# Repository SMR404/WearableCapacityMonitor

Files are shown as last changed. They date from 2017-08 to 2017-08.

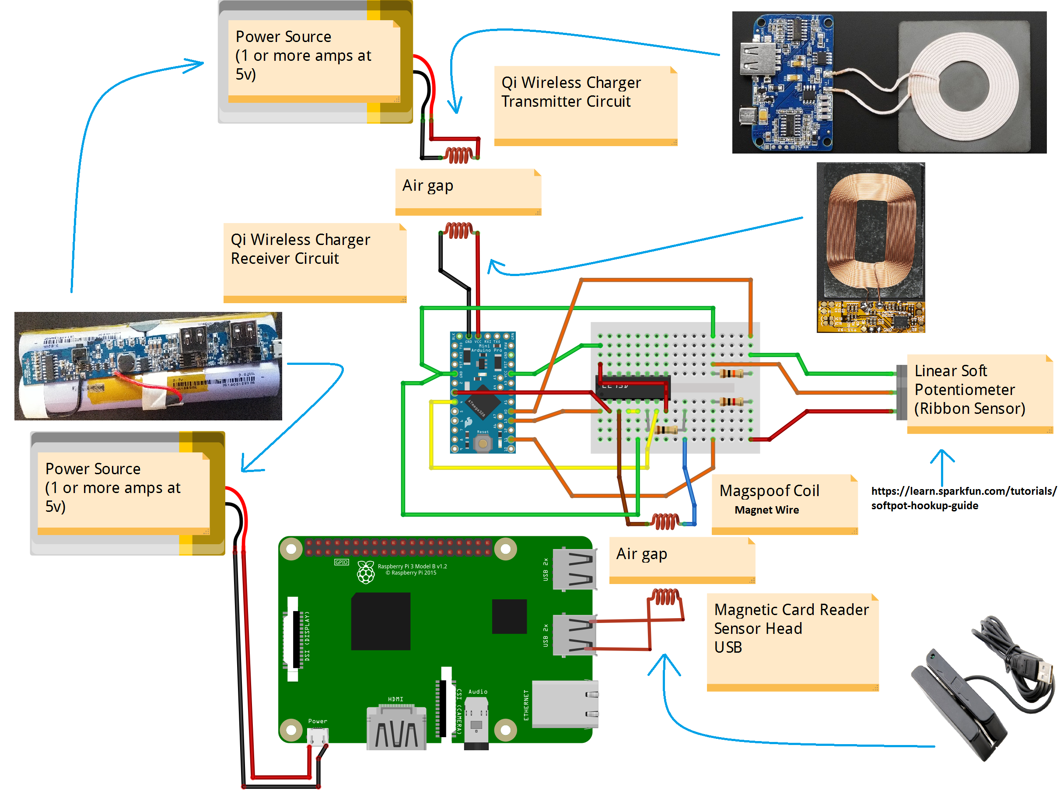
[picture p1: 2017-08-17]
diagrams/Diagram.png

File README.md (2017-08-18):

# BT_CapacityMonitor

# AR-15 Magazine Capacity Monitoring System (Proof of Concept)

This is a proof of concept for a method to display the number of rounds in an AR-15's magazine on an Android device or Android-Wear device using bluetooth for data transfer from Raspberry Pi to android and using a modified version of Samy Kamkar's (@samyk) magspoof for data transfer between the magazine and raspberry pi. Credit to @miaoski for his conversion of the magspoof's ATtiny85's code to arduino.

**Check out my video for more information, explanations, and pictures/video.**

General Overview of project + Demonstration: https://vid.me/MMtok

I'll try and get some new videos up discussing this idea and desired improvements in depth at a (hopefully soon) future date.

## *Flow of information*

The system is composed of several components and boards.
Below is the flow of infomation from the magazine to the user.

- **Component: On Magazine - Arduino Pro Mini (or similar) with a Magspoof magnetic Card emulator (magspoof)**

 &nbsp;&nbsp;&nbsp;&nbsp;&nbsp;&nbsp;&nbsp;&nbsp;&nbsp;&nbsp;&nbsp;&nbsp;&nbsp;&nbsp;&nbsp;&nbsp;&nbsp;&nbsp;|<br>
 &nbsp;&nbsp;&nbsp;&nbsp;&nbsp;&nbsp;&nbsp;&nbsp;&nbsp;&nbsp;&nbsp;&nbsp;&nbsp;&nbsp;&nbsp;&nbsp;&nbsp;&nbsp;|<br>
 &nbsp;&nbsp;&nbsp;&nbsp;&nbsp;&nbsp;&nbsp;&nbsp;&nbsp;&nbsp;&nbsp;&nbsp;&nbsp;&nbsp;&nbsp;&nbsp;&nbsp;&nbsp;| &nbsp;&nbsp;&nbsp;&nbsp;&nbsp;&nbsp;&nbsp;&nbsp;   *Data (ultra-low baud rate) is sent wirelessly from the magazine to the card reader via magspoof* <br>
 &nbsp;&nbsp;&nbsp;&nbsp;&nbsp;&nbsp;&nbsp;&nbsp;&nbsp;&nbsp;&nbsp;&nbsp;&nbsp;&nbsp;&nbsp;&nbsp;&nbsp;&nbsp;|<br>
 &nbsp;&nbsp;&nbsp;&nbsp;&nbsp;&nbsp;&nbsp;&nbsp;&nbsp;&nbsp;&nbsp;&nbsp;&nbsp;&nbsp;&nbsp;&nbsp;&nbsp;&nbsp;|<br>
 &nbsp;&nbsp;&nbsp;&nbsp;&nbsp;&nbsp;&nbsp;&nbsp;&nbsp;&nbsp;&nbsp;&nbsp;&nbsp;&nbsp;&nbsp;&nbsp;&nbsp;▼      

- **Component: On Rifle - Magnetic Card Reader connected as a usb keyboard to the Raspberry-pi (or similar)**

 &nbsp;&nbsp;&nbsp;&nbsp;&nbsp;&nbsp;&nbsp;&nbsp;&nbsp;&nbsp;&nbsp;&nbsp;&nbsp;&nbsp;&nbsp;&nbsp;&nbsp;&nbsp;|<br>
 &nbsp;&nbsp;&nbsp;&nbsp;&nbsp;&nbsp;&nbsp;&nbsp;&nbsp;&nbsp;&nbsp;&nbsp;&nbsp;&nbsp;&nbsp;&nbsp;&nbsp;&nbsp;|<br>
 &nbsp;&nbsp;&nbsp;&nbsp;&nbsp;&nbsp;&nbsp;&nbsp;&nbsp;&nbsp;&nbsp;&nbsp;&nbsp;&nbsp;&nbsp;&nbsp;&nbsp;&nbsp;|  &nbsp;&nbsp;&nbsp;&nbsp;&nbsp;&nbsp;&nbsp;&nbsp;&nbsp;&nbsp;     *Data is sent over bluetooth serial connection from the Raspberry-pi to android*
 <br>
&nbsp;&nbsp;&nbsp;&nbsp;&nbsp;&nbsp;&nbsp;&nbsp;&nbsp;&nbsp;&nbsp;&nbsp;&nbsp;&nbsp;&nbsp;&nbsp;&nbsp;&nbsp;|<br>
 &nbsp;&nbsp;&nbsp;&nbsp;&nbsp;&nbsp;&nbsp;&nbsp;&nbsp;&nbsp;&nbsp;&nbsp;&nbsp;&nbsp;&nbsp;&nbsp;&nbsp;&nbsp;|<br>
 &nbsp;&nbsp;&nbsp;&nbsp;&nbsp;&nbsp;&nbsp;&nbsp;&nbsp;&nbsp;&nbsp;&nbsp;&nbsp;&nbsp;&nbsp;&nbsp;&nbsp;▼   

- **Component: Android Wear or other android device (or similar)**

&nbsp;&nbsp;&nbsp;&nbsp;&nbsp;&nbsp;&nbsp;&nbsp;&nbsp;&nbsp;&nbsp;&nbsp;&nbsp;&nbsp;&nbsp;&nbsp;&nbsp;&nbsp;| <br>
&nbsp;&nbsp;&nbsp;&nbsp;&nbsp;&nbsp;&nbsp;&nbsp;&nbsp;&nbsp;&nbsp;&nbsp;&nbsp;&nbsp;&nbsp;&nbsp;&nbsp;&nbsp;|<br>
&nbsp;&nbsp;&nbsp;&nbsp;&nbsp;&nbsp;&nbsp;&nbsp;&nbsp;&nbsp;&nbsp;&nbsp;&nbsp;&nbsp;&nbsp;&nbsp;&nbsp;&nbsp;|&nbsp;&nbsp;&nbsp;&nbsp;&nbsp;&nbsp;&nbsp;&nbsp; *Data is displayed to user*
<br>
&nbsp;&nbsp;&nbsp;&nbsp;&nbsp;&nbsp;&nbsp;&nbsp;&nbsp;&nbsp;&nbsp;&nbsp;&nbsp;&nbsp;&nbsp;&nbsp;&nbsp;&nbsp;|<br>
&nbsp;&nbsp;&nbsp;&nbsp;&nbsp;&nbsp;&nbsp;&nbsp;&nbsp;&nbsp;&nbsp;&nbsp;&nbsp;&nbsp;&nbsp;&nbsp;&nbsp;&nbsp;|<br>
&nbsp;&nbsp;&nbsp;&nbsp;&nbsp;&nbsp;&nbsp;&nbsp;&nbsp;&nbsp;&nbsp;&nbsp;&nbsp;&nbsp;&nbsp;&nbsp;&nbsp;▼ <br>

- **Component: Eyeballs (or similar /s)**

## The info from this point on is copied from the README.md files in each immediate subfolder in this project. Navigate to those subfolders to view each topic's information by itself.

# Topic: Android
This repo has the source code for an android-wear and regular android device app. It's more convenient to test and debug from a regular android device app in my experience.
<br>
<br>
I ran out of time to really make a competent application for android (First time android developer, here).
The current android-wear program has only been tested on my Moto 360 sport and has no menu to select the Bluetooth address of the raspberry pi
to which it connects.
This means that the bluetooth address of the pi is hardcoded (gasp) into the program and **you need to change it and then build the .apk yourself**. This is pretty much a vital feature that is missing from the app.

Ideas for improvement (on android-wear):
----------------------------------
- 1. The ability to swipe between several screens which would contain some of the below features
- 2. Bluetooth Address selection screen
- 3. Day/Night mode (on an options screen)
- 4. Power down option for rapsberry pi on options screen (requires alteration to the pi's python program)
- 5. Move the connect/disconnect button to it's own screen and auto-navigate to the capacity value display screen on connection

Debugging over Bluetooth
----------------------
If you don't know how to upload an app to an android wear device without a usb port (like the moto 360 sport), you should get familiar with bluetooth debugging.

https://medium.com/@jcdelvalle/android-wear-bluetooth-debugging-quickly-guide-ef279b84169c

Follow this guide and you should be able to upload the built apk to the watch.

**Important Note:** If you can't get adb to recognize your phone, make sure that you have connected your phone as a camera device. If that doesn't work, then try all the other types of devices it can connect as.

# Topic: Arduino
Upload the sketch to your arduino (pro mini). 
You can use @miaoski's code for debugging and making sure your
magspoof circuit works (just be aware that the digital pins used his code are different numbers).

https://github.com/miaoski/magspoof

Use the softpot test file to calibrate your magazine by putting an increasing number of rounds into the magazine
and recording the analog readings and moving them into the 1d array in the arduino code.

Reference the diagram in this repo or in @miaoski's magspoof repo to make sure that your circuit is right.
I used 24 AWG wire to make the coil for data transfer.

# Topic: Raspberry Pi BT Communication Scripts
How the communication script is setup
----------------------------------------
The communication between the android device and the raspberry-pi is enabled
through a bash script that calls two python programs through a virtual terminal. 
This script launches on the start of the desktop environment.

The desktop enviromnent seems necessary because if the bash script is called (through cron or rc.local) if
the pi has booted to command line, the magentic card reader (which is a usb keyboard)
has no interactive window to output to (input() and raw_input() throw an EOF error).

This issue could possibly be solved if the two python programs were consolidated
into one program by using multiprocessing, and then monitoring usb input at a lower level (maybe using evdev or something similar?) allowing the pi script to function properly
in CLI.

Preparing the Pi
--------------------------
Make sure you are fully updated.
Make sure that the proper bluetooth libraries are installed. Follow the first part of this guide I found to make sure you have the right stuff installed. 

   `sudo apt-get dist-upgrade` <br>
   `sudo apt-get update`<br>
   `sudo apt-get upgrade`<br>
   `sudo apt-get install bluez pi-bluetooth python-bluez`<br>

How to get the script to run on boot
-------------------------------------
1. Make sure that the android device and the pi have been paired and trusted with one another (use Raspbian GUI or bluetooth-ctl).
   <br>
   *This is a permanent action (meaning it survives across reboots) that makes it so that the pi and the android device can open a serial    connection without issues.*

2. Move the magCapacityScripts folder (from github) to the /pi/home/ directory
   - run **sudo chmod +x bluetoothCommunicationScript.sh** while in the same directory as it

3. Move launch.sh (from github) to the /pi/home/ directory. 
   - run **sudo chmod +x launch.sh** while in the same directory as it
   
4. Edit the LXDE autostart file so that launch.sh runs on boot:
   
   - add these lines
   
   **cd /home/pi**
    <br>
    **sudo ./launch.sh**
    <br>
    
    - run **sudo chmod +x launch.sh** while in the same directory as it (should not be necessary, only a redundant precaution)

In this setup, the communication script is run on the start of the desktop gui.

**Note:** For some reason, without launch.sh as an intermediary shell script, autostart does not function properly (as in, bluetoothCommunicationScript.sh is called directly from autostart). In the configuration without launch.sh, autostart functions fine if called by the user, but not if it is run on boot. Not sure why.

**Important Info:** If a modified magazine has been placed into the rifle when the pi is powered, the magstripe reader attempts to send data to the pi's usb port as it is booting. The SHIFT key is pressed by the magstripe reader when it sends it's character string through the usb port. Incidentally, the key to boot to recovery is the SHIFT key. This means that, if the 'boot to recovery by pressing shift' option is enabled, the pi will boot to recovery, probably without you noticing it if you don't have it connected to a monitor. The scripts will not run in this scenario. This issue could likely be fixed by removing the option to boot to recovery, which as far as I am aware, is only something that can be done during the raspbian installation, but I have not looked into it.

# Topic: Solid Modeling
Solid Modeling Files
----------------
Note that this assembly simply represents a proof of concept and has not been designed to fulfill any practical purpose.

It seems that the Raspberry Pi model (and only that model) does not want to load properly when the STEP or IGES file is imported. If you want to place it into the assembly again, I have a zip of that model here. I got it from https://grabcad.com/library/raspberry-pi-3-6

I had to modify the lower receiver to fit the Qi Wireless Charging Ciruit and the Magnetic card reader in a semi-acceptable fashion.
In this assembly, the lower receiver is a modified (read: has sections manually and physically cut away with a power tool) version of the New Frontier LW-15 Polymer Lower Receiver (https://newfrontierarmory.com/shop/lw-15-complete-polymer-lower-receiver/). 

**ONE REALLY IMPORTANT NOTE:**
-----------------------------
I chose this receiver because polymer is easier to cut and because it was a relatively cheap receiver, and **ABOVE ALL**, because *the serial number is located away from where the modifcations take place, and none of the 3d Printed attached parts obfuscate it.*

The serial number is near the fire selector lever, and is not on the exterior of the magazine well like you will find on many other AR-15 lower receivers.

It's a really big deal that you don't alter or cover up the serial number in any way at all if you have bought a lower receiver that has such a serial number associated with it. If you have completed an 80% complete polymer lower yourself, then it's not a problem since there is no serial number assigned to it.

This is the responsibility of you as the person who is modifying their rifle, not mine. Fair warning.

# Topic: Diagrams

Hopefully these diagrams, coupled with the videos and photos, are descriptive enough.

## Items for purchase:
- L293 Motor Driver https://www.amazon.com/NDRTJM-MSTL2930-L293D-Stepper-Driver/dp/B008XCGLNM

<br>

- Raspberry Pi 3 or Raspberry Pi Zero W

<br>

- Arduino Pro Mini or other Arduino

<br>

- Android Wear device or other Android Device (with bluetooth)

<br>

- Polymer Lower Receiver (like a New Frontier LW-15, https://newfrontierarmory.com/shop/lw-15-complete-polymer-lower-receiver/)

<br>

- Qi Wireless Charging Transmitter https://www.adafruit.com/product/2162

<br>

- Qi Wireless Charging Receiver https://www.adafruit.com/product/1901

<br>

- Magnetic Card Reader http://a.co/55RirJM

<br>

- 10 kΩ, 1 kΩ and 1Ω resistors

<br>
 
 - Battery Pack with 2 ports, both of which supplying at least 1 amp each at 5v (2 amps at 5v is preferred for the port powering the Qi wireless Charger Transmitter.
 
 <br>
 
  - BreadBoard or permaProto board (preferred)
 
 <br>
 
 - Jumper Cables or other small wires
 
 <br>
 
 - Magnet Wire (24 AWG is what I used)
 
 <br>
 
 - Bolts or Machine screws of approximate outer thread diameter of 0.3 mm (I don't know what I used, they were found leftovers)
 
 <br>
 
 - 3D printer and filament
 
  <br>
  <br>
  <br>
  
 These are just the items that are attached to/used with the gun. There are lots of other logistical items like arduino programmer chips and other things that you will need for this, but they are intuitive and are closely associated with the use of the above items.

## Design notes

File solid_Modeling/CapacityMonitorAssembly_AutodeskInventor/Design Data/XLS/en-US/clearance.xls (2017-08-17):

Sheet: Ansi Unified Screw Threads
I | Sort Order -1
Fastener Type | Size | Shaft Diameters |  |  | Head Dimensions
 |  | Close | Normal | Loose | Diameter | Depth/Angle | Head Type
Flat Head Machine Screw (82) | #0 | 0.0635 | 0.07 | 0.073 | 0.119 | 82 | 2
Flat Head Machine Screw (82) | #1 | 0.076 | 0.081 | 0.089 | 0.146 | 82 | 2
Flat Head Machine Screw (82) | #2 | 0.089 | 0.096 | 0.1065 | 0.172 | 82 | 2
Flat Head Machine Screw (82) | #3 | 0.104 | 0.11 | 0.12 | 0.199 | 82 | 2
Flat Head Machine Screw (82) | #4 | 0.116 | 0.1285 | 0.136 | 0.225 | 82 | 2
Flat Head Machine Screw (82) | #5 | 0.1285 | 0.136 | 0.154 | 0.252 | 82 | 2
Flat Head Machine Screw (82) | #6 | 0.144 | 0.1495 | 0.1695 | 0.279 | 82 | 2
Flat Head Machine Screw (82) | #8 | 0.1695 | 0.177 | 0.1935 | 0.332 | 82 | 2
Flat Head Machine Screw (82) | #10 | 0.196 | 0.201 | 0.221 | 0.385 | 82 | 2
Flat Head Machine Screw (82) | #12 | 0.221 | 0.228 | 0.246 | 0.438 | 82 | 2
Flat Head Machine Screw (82) | 1/4 | 0.257 | 0.266 | 0.2812 | 0.507 | 82 | 2
Flat Head Machine Screw (82) | 5/16 | 0.323 | 0.332 | 0.3437 | 0.635 | 82 | 2
Flat Head Machine Screw (82) | 3/8 | 0.386 | 0.397 | 0.4062 | 0.762 | 82 | 2
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

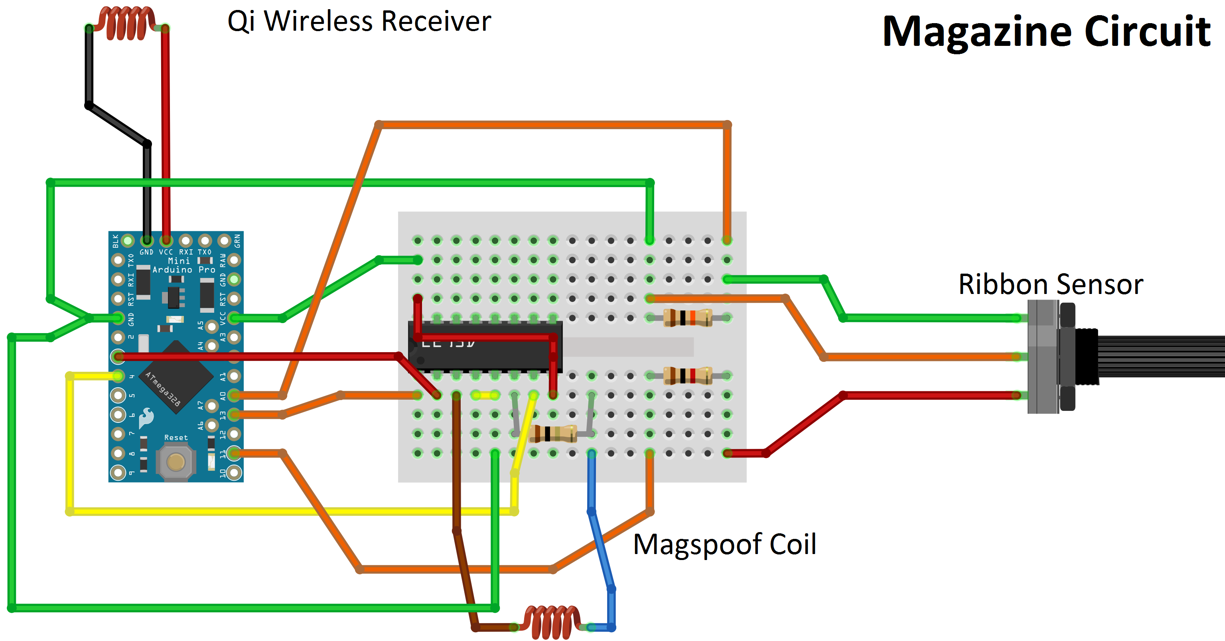
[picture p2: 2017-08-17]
diagrams/Diagram_MagazineOnly.png

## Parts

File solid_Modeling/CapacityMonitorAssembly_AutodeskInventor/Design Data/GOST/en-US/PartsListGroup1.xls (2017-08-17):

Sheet: Лист 1
Инв. № подл |  |  |  | Подп. и дата | Взам. инв. № | Инв. № дубл. |  |  | Подп. и дата
Формат | Зона | Поз. | Обозначение |  |  |  | Наименование |  |  |  |  |  | Кол. на исполнение
 |  |  |  |  |  |  |  |  |  |  |  | Лит.
 |  |  |  |  |  |  |  |  |  |  |  | Код
 |  |  |  |  |  |  |  | Изм. | Лист | № докум | Подпись |  | Дата
 |  |  |  |  |  |  |  | Разраб.
 |  |  |  |  |  |  |  | Пров.
 |  |  |  |  |  |  |  | Н.контр
 |  |  |  |  |  |  |  | Утв.
 |  |  |  |  |  |  |  |  |  |  |  |  |  | Копировал

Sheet: Лист 2
Инв. № подл |  |  |  | Подп. и дата | Взам. инв. № | Инв. № дубл. |  |  | Подп. и дата
Формат | Зона | Поз. | Обозначение |  |  |  | Наименование |  |  |  |  | Кол. на исполнение
 |  |  |  |  |  |  |  | Изм. | Лист | № докум. | Подп. | Дата
 |  |  |  |  |  |  |  |  |  |  |  |  | Копировал
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

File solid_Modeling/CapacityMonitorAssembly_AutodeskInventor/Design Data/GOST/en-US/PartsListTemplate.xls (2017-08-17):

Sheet: Лист 1
 | Формат | Зона |  | Поз. |  | Обозначение |  |  |  | Наименование |  |  |  | Кол. | Приме-чание
Подп. и дата
Инв. № дубл.
Взам. инв. №
Подп. и дата
 | Изм. |  | Лист |  | № докум |  | Подпись | Дата
Инв. № подл | Разраб. |  |  |  |  |  |  |  |  |  | Литера |  | Лист |  |  | Листов
 | Пров.
 | Н.контр
 | Утв.
 |  |  |  |  |  |  |  |  | Копировал |  |  | Формат А4

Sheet: Лист 2
 | Формат | Зона |  | Поз. |  | Обозначение |  |  |  | Наименование |  | Кол. | Приме-чание
Подп. и дата
Инв. № дубл.
Взам. инв. №
Подп. и дата
Инв. № подл
 | Изм. |  | Лист |  | № докум. |  | Подп. |  | Дата
 |  |  |  |  |  |  |  | Копировал |  |  | Формат А4
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

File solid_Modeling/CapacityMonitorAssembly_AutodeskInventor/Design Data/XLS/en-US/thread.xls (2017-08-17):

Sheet: Inch Tapping Threads
I Q X | Inch Tapping Threads |  | Sort Order - 5 |  | External |  |  |  |  |  |  | Internal
 |  |  |  |  |  | Major Dia |  | Pitch Dia |  | Minor Dia |  |  | Minor Dia |  | Pitch Dia |  | Major Dia |  | Tap Drill
Size | Size Suffix | Thread Designation | Custom Thread Designation | TPI | Class | Max | Min | Max | Min | Max | Min | Class | Min | Max | Min | Max | Min | Max | Basic
0.0600 |  | 0-48 | 0-48 | 48 | 2B | 0.0600 | 0.0540 | 0.0480 | 0.0435 | 0.0360 | 0.0330
0.0730 |  | 1-42 | 1-42 | 42 | 2B | 0.0750 | 0.0690 | 0.0620 | 0.0575 | 0.0490 | 0.0460
0.0860 |  | 2-32 | 2-32 | 32 | 2B | 0.0880 | 0.0820 | 0.0760 | 0.0710 | 0.0640 | 0.0600
0.0990 |  | 3-28 | 3-28 | 28 | 2B | 0.1010 | 0.0950 | 0.0880 | 0.0830 | 0.0750 | 0.0710
0.1120 |  | 4-24 | 4-24 | 24 | 2B | 0.1140 | 0.1080 | 0.1000 | 0.0950 | 0.0860 | 0.0820
0.1250 |  | 5-20 | 5-20 | 20 | 2B | 0.1300 | 0.1230 | 0.1120 | 0.1065 | 0.0940 | 0.0900
0.1380 |  | 6-20 | 6-20 | 20 | 2B | 0.1390 | 0.1320 | 0.1215 | 0.1155 | 0.1040 | 0.0990
0.1510 |  | 7-19 | 7-19 | 19 | 2B | 0.1540 | 0.1470 | 0.1345 | 0.1280 | 0.1150 | 0.1090
0.1640 |  | 8-18 | 8-18 | 18 | 2B | 0.1660 | 0.1590 | 0.1440 | 0.1375 | 0.1220 | 0.1160
0.1900 |  | 10-16 | 10-16 | 16 | 2B | 0.1890 | 0.1820 | 0.1650 | 0.1585 | 0.1410 | 0.1350
0.2160 |  | 12-14 | 12-14 | 14 | 2B | 0.2150 | 0.2080 | 0.1895 | 0.1825 | 0.1640 | 0.1570
0.2420 |  | 14-14 | 14-14 | 14 | 2B | 0.2410 | 0.2340 | 0.2130 | 0.2060 | 0.1850 | 0.1780
0.2500 |  | 1/4-14 | 1/4-14 | 14 | 2B | 0.2460 | 0.2370 | 0.2190 | 0.2110 | 0.1920 | 0.1850
0.3125 |  | 5/16-12 | 5/16-12 | 12 | 2B | 0.3150 | 0.3060 | 0.2795 | 0.2710 | 0.2440 | 0.2360
0.3750 |  | 3/8-12 | 3/8-12 | 12 | 2B | 0.3800 | 0.3710 | 0.3445 | 0.3350 | 0.3090 | 0.2990
0.4375 |  | 7/16-10 | 7/16-10 | 10 | 2B | 0.4400 | 0.4290 | 0.3995 | 0.3890 | 0.3590 | 0.3490
0.5000 |  | 1/2-10 | 1/2-10 | 10 | 2B | 0.5040 | 0.4930 | 0.4635 | 0.4530 | 0.4230 | 0.4130

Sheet: Metric Forming Screw Threads
M P X | Metric Forming Screw Threads |  | Sort Order - 6 |  | External |  |  |  |  |  |  | Internal
 |  |  |  |  |  | Major Dia |  | Pitch Dia |  | Minor Dia |  |  | Minor Dia |  | Pitch Dia |  | Major Dia |  | Tap Drill
Size | Size Suffix | Thread Designation | Custom Thread Designation | Pitch | Class | Max | Min | Max | Min | Max | Min | Class | Min | Max | Min | Max | Min | Max | Basic
1.5 |  | 1.5x0.5 | 1.5x0.5 | 0.5 | 6g | 1.520 | 1.380 | 1.215 | 1.110 | 0.910 | 0.840
1.5 |  | ST1.5x0.5 | ST1.5x0.5 | 0.5 | 6g | 1.520 | 1.380 | 1.215 | 1.110 | 0.910 | 0.840
1.9 |  | 1.9x0.6 | 1.9x0.6 | 0.6 | 6g | 1.900 | 1.760 | 1.570 | 1.465 | 1.240 | 1.170
1.9 |  | ST1.9x0.6 | ST1.9x0.6 | 0.6 | 6g | 1.900 | 1.760 | 1.570 | 1.465 | 1.240 | 1.170
2.2 |  | 2.2x0.8 | 2.2x0.8 | 0.8 | 6g | 2.240 | 2.100 | 1.935 | 1.810 | 1.630 | 1.520
2.2 |  | ST2.2x0.8 | ST2.2x0.8 | 0.8 | 6g | 2.240 | 2.100 | 1.935 | 1.810 | 1.630 | 1.520
2.6 |  | 2.6x0.9 | 2.6x0.9 | 0.9 | 6g | 2.570 | 2.430 | 2.235 | 2.115 | 1.900 | 1.800
2.6 |  | ST2.6x0.9 | ST2.6x0.9 | 0.9 | 6g | 2.570 | 2.430 | 2.235 | 2.115 | 1.900 | 1.800
2.9 |  | 2.9x1 | 2.9x1 | 1 | 6g | 2.900 | 2.760 | 2.540 | 2.420 | 2.180 | 2.080
2.9 |  | 2.9x1.1 | 2.9x1.1 | 1.1 | 6g | 2.900 | 2.760 | 2.540 | 2.420 | 2.180 | 2.080
2.9 |  | ST2.9x1.1 | ST2.9x1.1 | 1.1 | 6g | 2.900 | 2.760 | 2.540 | 2.420 | 2.180 | 2.080
2.9 |  | 2.9x1.3 | 2.9x1.3 | 1.3 | 6g | 2.900 | 2.720 | 2.540 | 2.355 | 1.890 | 1.700
2.9 |  | 2.9x1.4 | 2.9x1.4 | 1.4 | 6g | 2.900 | 2.720 | 2.340 | 2.175 | 1.780 | 1.630
3.3 |  | 3.3x1.3 | 3.3x1.3 | 1.3 | 6g | 3.300 | 3.120 | 2.795 | 2.665 | 2.290 | 2.210
3.3 |  | ST3.3x1.3 | ST3.3x1.3 | 1.3 | 6g | 3.300 | 3.120 | 2.795 | 2.665 | 2.290 | 2.210
3.5 |  | 3.5x1.3 | 3.5x1.3 | 1.3 | 6g | 3.530 | 3.350 | 3.085 | 2.930 | 2.640 | 2.510
3.5 |  | ST3.5x1.3 | ST3.5x1.3 | 1.3 | 6g | 3.530 | 3.350 | 3.085 | 2.930 | 2.640 | 2.510
3.5 |  | 3.5x1.6 | 3.5x1.6 | 1.6 | 6g | 3.530 | 3.350 | 2.920 | 2.755 | 2.310 | 2.160
3.5 |  | 3.5x3.2 | 3.5x3.2 | 3.2 | 6g | 3.530 | 3.310 | 2.800 | 2.600 | 2.070 | 1.890
3.9 |  | 3.9x1.3 | 3.9x1.3 | 1.3 | 6g | 3.910 | 3.730 | 3.415 | 3.250 | 2.920 | 2.770
3.9 |  | ST3.9x1.3 | ST3.9x1.3 | 1.3 | 6g | 3.910 | 3.730 | 3.415 | 3.250 | 2.920 | 2.770
3.9 |  | 3.9x1.6 | 3.9x1.6 | 1.6 | 6g | 3.910 | 3.730 | 3.300 | 3.135 | 2.690 | 2.540
3.9 |  | 3.9x3.2 | 3.9x3.2 | 3.2 | 6g | 3.910 | 3.690 | 3.180 | 2.980 | 2.450 | 2.270
4.2 |  | 4.2x1.4 | 4.2x1.4 | 1.4 | 6g | 4.220 | 4.040 | 3.660 | 3.495 | 3.100 | 2.950
4.2 |  | ST4.2x1.4 | ST4.2x1.4 | 1.4 | 6g | 4.220 | 4.040 | 3.660 | 3.495 | 3.100 | 2.950
4.2 |  | 4.2x1.6 | 4.2x1.6 | 1.6 | 6g | 4.220 | 4.040 | 3.610 | 3.445 | 3.000 | 2.850
4.2 |  | 4.2x3.2 | 4.2x3.2 | 3.2 | 6g | 4.220 | 4.000 | 3.380 | 3.180 | 2.540 | 2.360
4.8 |  | 4.8x1.6 | 4.8x1.6 | 1.6 | 6g | 4.800 | 4.620 | 4.190 | 4.025 | 3.580 | 3.430
4.8 |  | ST4.8x1.6 | ST4.8x1.6 | 1.6 | 6g | 4.800 | 4.620 | 4.190 | 4.025 | 3.580 | 3.430
4.8 |  | 4.8x1.8 | 4.8x1.8 | 1.8 | 6g | 4.800 | 4.620 | 4.065 | 3.885 | 3.330 | 3.150
4.8 |  | 4.8x3.2 | 4.8x3.2 | 3.2 | 6g | 4.800 | 4.580 | 3.960 | 3.760 | 3.120 | 2.940
5.5 |  | 5.5x1.8 | 5.5x1.8 | 1.8 | 6g | 5.460 | 5.280 | 4.815 | 4.635 | 4.170 | 3.990
5.5 |  | ST5.5x1.8 | ST5.5x1.8 | 1.8 | 6g | 5.460 | 5.280 | 4.815 | 4.635 | 4.170 | 3.990
6.3 |  | 6.3x1.8 | 6.3x1.8 | 1.8 | 6g | 6.250 | 6.030 | 5.565 | 5.365 | 4.880 | 4.700
6.3 |  | ST6.3x1.8 | ST6.3x1.8 | 1.8 | 6g | 6.250 | 6.030 | 5.565 | 5.365 | 4.880 | 4.700
8.0 |  | 8x2.1 | 8x2.1 | 2.1 | 6g | 8.000 | 7.780 | 7.100 | 6.885 | 6.200 | 5.990
8.0 |  | ST8x2.1 | ST8x2.1 | 2.1 | 6g | 8.000 | 7.780 | 7.100 | 6.885 | 6.200 | 5.990
9.5 |  | 9.5x2.1 | 9.5x2.1 | 2.1 | 6g | 9.650 | 9.430 | 8.750 | 8.510 | 7.850 | 7.590
9.5 |  | ST9.5x2.1 | ST9.5x2.1 | 2.1 | 6g | 9.650 | 9.430 | 8.750 | 8.510 | 7.850 | 7.590

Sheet: ISO Pipe Threads
M Q | ISO Pipe Threads |  | Sort Order - 9 |  | External |  |  |  |  |  |  | Internal
 |  |  |  |  |  | Major Dia |  | Pitch Dia |  | Minor Dia |  |  | Minor Dia |  | Pitch Dia |  | Major Dia |  | Tap Drill | Thread Depth | Thread Runouts
Size | Size Suffix | Thread Designation | Custom Thread Designation | TPI | Class | Max | Min | Max | Min | Max | Min | Class | Min | Max | Min | Max | Min | Max | Basic
7.723 |  | G7.723x0.907 | G 1/16 | 28 | A | 7.723 | 7.509 | 7.142 | 7.035 | 6.561 |  |  | 6.561 | 6.834 | 7.142 | 7.249 | 7.723 |  | 1.5875 | 15.446 | 4.5000
7.723 |  | G7.723x0.907 | G 1/16 | 28 | B | 7.723 | 7.509 | 7.142 | 6.928 | 6.561
9.728 |  | G9.728x0.907 | G 1/8 | 28 | A | 9.728 | 9.514 | 9.147 | 9.040 | 8.566 |  |  | 8.566 | 8.848 | 9.147 | 9.254 | 9.728 |  | 3.1750 | 19.456 | 4.5000
9.728 |  | G9.728x0.907 | G 1/8 | 28 | B | 9.728 | 9.514 | 9.147 | 8.933 | 8.566
13.157 |  | G13.157x1.337 | G 1/4 | 19 | A | 13.157 | 12.907 | 12.301 | 12.176 | 11.445 |  |  | 11.445 | 11.89 | 12.301 | 12.426 | 13.157 |  | 6.3500 | 26.314 | 6.5000
13.157 |  | G13.157x1.337 | G 1/4 | 19 | B | 13.157 | 12.907 | 12.301 | 12.051 | 11.445
16.662 |  | G16.662x1.337 | G 3/8 | 19 | A | 16.662 | 16.412 | 15.806 | 15.681 | 14.950 |  |  | 14.95 | 15.395 | 15.806 | 15.931 | 16.662 |  | 9.5250 | 33.324 | 6.5000
16.662 |  | G16.662x1.337 | G 3/8 | 19 | B | 16.662 | 16.412 | 15.806 | 15.556 | 14.950
20.955 |  | G20.955x1.814 | G 1/2 | 14 | A | 20.955 | 20.671 | 19.793 | 19.651 | 18.631 |  |  | 18.631 | 19.172 | 19.793 | 19.935 | 20.955 |  | 12.7000 | 41.910 | 8.5000
20.955 |  | G20.955x1.814 | G 1/2 | 14 | B | 20.955 | 20.671 | 19.793 | 19.509 | 18.631
22.911 |  | G22.911x1.814 | G 5/8 | 14 | A | 22.911 | 22.627 | 21.749 | 21.607 | 20.587 |  |  | 20.587 | 21.128 | 21.749 | 21.891 | 22.911 |  |  | 45.822 | 8.5000
22.911 |  | G22.911x1.814 | G 5/8 | 14 | B | 22.911 | 22.627 | 21.749 | 21.465 | 20.587
26.441 |  | G26.441x1.814 | G 3/4 | 14 | A | 26.441 | 26.157 | 25.279 | 25.137 | 24.117 |  |  | 24.117 | 24.658 | 25.279 | 25.421 | 26.441 |  | 15.8750 | 52.882 | 8.5000
26.441 |  | G26.441x1.814 | G 3/4 | 14 | B | 26.441 | 26.157 | 25.279 | 24.995 | 24.117
30.201 |  | G30.201x1.814 | G 7/8 | 14 | A | 30.201 | 29.917 | 29.039 | 28.897 | 27.877 |  |  | 27.877 | 28.418 | 29.039 | 29.181 | 30.201 |  | 22.2250 | 60.402 | 8.5000
30.201 |  | G30.201x1.814 | G 7/8 | 14 | B | 30.201 | 29.917 | 29.039 | 28.755 | 27.877
33.249 |  | G33.249x2.309 | G 1 | 11 | A | 33.249 | 32.889 | 31.770 | 31.590 | 30.291 |  |  | 30.291 | 30.931 | 31.77 | 31.95 | 33.249 |  | 25.4000 | 66.498 | 10.0000
33.249 |  | G33.249x2.309 | G 1 | 11 | B | 33.249 | 32.889 | 31.770 | 31.410 | 30.291
37.897 |  | G37.897x2.309 | G 1 1/8 | 11 | A | 37.897 | 37.537 | 36.418 | 36.238 | 34.939 |  |  | 34.939 | 35.579 | 36.418 | 36.598 | 37.897 |  | 28.5750 | 75.794 | 10.0000
37.897 |  | G37.897x2.309 | G 1 1/8 | 11 | B | 37.897 | 37.537 | 36.418 | 36.058 | 34.939
41.910 |  | G41.91x2.309 | G 1 1/4 | 11 | A | 41.910 | 41.550 | 40.431 | 40.251 | 38.952 |  |  | 38.952 | 39.592 | 40.431 | 40.611 | 41.910 |  | 31.7500 | 83.820 | 10.0000
41.910 |  | G41.91x2.309 | G 1 1/4 | 11 | B | 41.910 | 41.550 | 40.431 | 40.071 | 38.952
47.803 |  | G47.803x2.309 | G 1 1/2 | 11 | A | 47.803 | 47.443 | 46.324 | 46.144 | 44.845 |  |  | 44.845 | 45.485 | 46.324 | 46.504 | 47.803 |  | 38.1000 | 95.606 | 10.0000
47.803 |  | G47.803x2.309 | G 1 1/2 | 11 | B | 47.803 | 47.443 | 46.324 | 45.964 | 44.845
53.746 |  | G53.746x2.309 | G 1 3/4 | 11 | A | 53.746 | 53.386 | 52.267 | 52.087 | 50.788 |  |  | 50.788 | 51.428 | 52.267 | 52.447 | 53.746 |  | 44.4500 | 107.492 | 10.0000
53.746 |  | G53.746x2.309 | G 1 3/4 | 11 | B | 53.746 | 53.386 | 52.267 | 51.907 | 50.788
59.614 |  | G59.614x2.309 | G 2 | 11 | A | 59.614 | 59.254 | 58.135 | 57.955 | 56.656 |  |  | 56.656 | 57.296 | 58.135 | 58.315 | 59.614 |  | 50.8000 | 119.228 | 10.0000
59.614 |  | G59.614x2.309 | G 2 | 11 | B | 59.614 | 59.254 | 58.135 | 57.775 | 56.656
65.710 |  | G65.71x2.309 | G 2 1/4 | 11 | A | 65.710 | 65.276 | 64.231 | 64.014 | 62.752 |  |  | 62.752 | 63.392 | 64.231 | 64.448 | 65.710 |  | 57.1500 | 131.420 | 10.0000
65.710 |  | G65.71x2.309 | G 2 1/4 | 11 | B | 65.710 | 65.276 | 64.231 | 63.797 | 62.752
75.184 |  | G75.184x2.309 | G 2 1/2 | 11 | A | 75.184 | 74.750 | 73.705 | 73.488 | 72.226 |  |  | 72.226 | 72.866 | 73.705 | 73.922 | 75.184 |  |  | 150.368 | 10.0000
75.184 |  | G75.184x2.309 | G 2 1/2 | 11 | B | 75.184 | 74.750 | 73.705 | 73.271 | 72.226
81.534 |  | G81.534x2.309 | G 2 3/4 | 11 | A | 81.534 | 81.100 | 80.055 | 79.838 | 78.576 |  |  | 78.576 | 79.216 | 80.055 | 80.272 | 81.534 |  | 69.8500 | 163.068 | 10.0000
81.534 |  | G81.534x2.309 | G 2 3/4 | 11 | B | 81.534 | 81.100 | 80.055 | 79.621 | 78.576
87.884 |  | G87.884x2.309 | G 3 | 11 | A | 87.884 | 87.450 | 86.405 | 86.188 | 84.926 |  |  | 84.926 | 85.566 | 86.405 | 86.622 | 87.884 |  | 76.2000 | 175.768 | 10.0000
87.884 |  | G87.884x2.309 | G 3 | 11 | B | 87.884 | 87.450 | 86.405 | 85.971 | 84.926
100.330 |  | G100.33x2.309 | G 3 1/2 | 11 | A | 100.330 | 99.896 | 98.851 | 98.634 | 97.372 |  |  | 97.372 | 98.012 | 98.851 | 99.068 | 100.330 |  | 88.9000 | 200.660 | 10.0000
100.330 |  | G100.33x2.309 | G 3 1/2 | 11 | B | 100.330 | 99.896 | 98.851 | 98.417 | 97.372
113.030 |  | G113.03x2.309 | G 4 | 11 | A | 113.030 | 112.596 | 111.551 | 111.334 | 110.072 |  |  | 110.072 | 110.712 | 111.551 | 111.768 | 113.030 |  | 101.6000 | 226.060 | 10.0000
113.030 |  | G113.03x2.309 | G 4 | 11 | B | 113.030 | 112.596 | 111.551 | 111.117 | 110.072
125.730 |  | G125.73x2.309 | G 4 1/2 | 11 | A | 125.730 | 125.296 | 124.251 | 124.034 | 122.772 |  |  | 122.772 | 123.412 | 124.251 | 124.468 | 125.730 |  | 114.3000 | 251.460 | 10.0000
125.730 |  | G125.73x2.309 | G 4 1/2 | 11 | B | 125.730 | 125.296 | 124.251 | 123.817 | 122.772
138.430 |  | G138.43x2.309 | G 5 | 11 | A | 138.430 | 137.996 | 136.951 | 136.734 | 135.472 |  |  | 135.472 | 136.112 | 136.951 | 137.168 | 138.430 |  | 127.0000 | 276.860 | 10.0000
138.430 |  | G138.43x2.309 | G 5 | 11 | B | 138.430 | 137.996 | 136.951 | 136.517 | 135.472
151.130 |  | G151.13x2.309 | G 5 1/2 | 11 | A | 151.130 | 150.696 | 149.651 | 149.434 | 148.172 |  |  | 148.172 | 148.812 | 149.651 | 149.868 | 151.130 |  | 139.7000 | 302.260 | 10.0000
151.130 |  | G151.13x2.309 | G 5 1/2 | 11 | B | 151.130 | 150.696 | 149.651 | 149.217 | 148.172
163.830 |  | G163.83x2.309 | G 6 | 11 | A | 163.830 | 163.396 | 162.351 | 162.134 | 160.872 |  |  | 160.872 | 161.512 | 162.351 | 162.568 | 163.830 |  | 152.4000 | 327.660 | 10.0000
163.830 |  | G163.83x2.309 | G 6 | 11 | B | 163.830 | 163.396 | 162.351 | 161.917 | 160.872

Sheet: JIS Pipe Threads
M Q | JIS Pipe Threads |  | Sort Order -12 |  | External |  |  |  |  |  |  | Internal
 |  |  |  |  |  | Major Dia |  | Pitch Dia |  | Minor Dia |  |  | Minor Dia |  | Pitch Dia |  | Major Dia |  | Tap Drill | Thread Depth | Thread Runouts
Size | Size Suffix | Thread Designation | Custom Thread Designation | TPI | Class | Max | Min | Max | Min | Max | Min | Class | Min | Max | Min | Max | Min | Max | Basic |  | Basic
7.723 |  | G7.723x0.907 | G 1/16 | 28 | A | 7.723 | 7.509 | 7.142 | 7.035 | 6.561 |  |  | 6.561 | 6.834 | 7.142 | 7.249 | 7.723 |  | 1.5875 | 15.446 | 4.5000
7.723 |  | G7.723x0.907 | G 1/16 | 28 | B | 7.723 | 7.509 | 7.142 | 6.928 | 6.561
9.728 |  | G9.728x0.907 | G 1/8 | 28 | A | 9.728 | 9.514 | 9.147 | 9.040 | 8.566 |  |  | 8.566 | 8.848 | 9.147 | 9.254 | 9.728 |  | 3.1750 | 19.456 | 4.5000
9.728 |  | G9.728x0.907 | G 1/8 | 28 | B | 9.728 | 9.514 | 9.147 | 8.933 | 8.566
13.157 |  | G13.157x1.337 | G 1/4 | 19 | A | 13.157 | 12.907 | 12.301 | 12.176 | 11.445 |  |  | 11.445 | 11.89 | 12.301 | 12.426 | 13.157 |  | 6.3500 | 26.314 | 6.5000
13.157 |  | G13.157x1.337 | G 1/4 | 19 | B | 13.157 | 12.907 | 12.301 | 12.051 | 11.445
16.662 |  | G16.662x1.337 | G 3/8 | 19 | A | 16.662 | 16.412 | 15.806 | 15.681 | 14.950 |  |  | 14.95 | 15.395 | 15.806 | 15.931 | 16.662 |  | 9.5250 | 33.324 | 6.5000
16.662 |  | G16.662x1.337 | G 3/8 | 19 | B | 16.662 | 16.412 | 15.806 | 15.556 | 14.950
20.955 |  | G20.955x1.814 | G 1/2 | 14 | A | 20.955 | 20.671 | 19.793 | 19.651 | 18.631 |  |  | 18.631 | 19.172 | 19.793 | 19.935 | 20.955 |  | 12.7000 | 41.910 | 8.5000
20.955 |  | G20.955x1.814 | G 1/2 | 14 | B | 20.955 | 20.671 | 19.793 | 19.509 | 18.631
22.911 |  | G22.911x1.814 | G 5/8 | 14 | A | 22.911 | 22.627 | 21.749 | 21.607 | 20.587 |  |  | 20.587 | 21.128 | 21.749 | 21.891 | 22.911 |  |  | 45.822 | 8.5000
22.911 |  | G22.911x1.814 | G 5/8 | 14 | B | 22.911 | 22.627 | 21.749 | 21.465 | 20.587
26.441 |  | G26.441x1.814 | G 3/4 | 14 | A | 26.441 | 26.157 | 25.279 | 25.137 | 24.117 |  |  | 24.117 | 24.658 | 25.279 | 25.421 | 26.441 |  | 15.8750 | 52.882 | 8.5000
26.441 |  | G26.441x1.814 | G 3/4 | 14 | B | 26.441 | 26.157 | 25.279 | 24.995 | 24.117
30.201 |  | G30.201x1.814 | G 7/8 | 14 | A | 30.201 | 29.917 | 29.039 | 28.897 | 27.877 |  |  | 27.877 | 28.418 | 29.039 | 29.181 | 30.201 |  | 22.2250 | 60.402 | 8.8000
30.201 |  | G30.201x1.814 | G 7/8 | 14 | B | 30.201 | 29.917 | 29.039 | 28.755 | 27.877
33.249 |  | G33.249x2.309 | G 1 | 11 | A | 33.249 | 32.889 | 31.770 | 31.590 | 30.291 |  |  | 30.291 | 30.931 | 31.77 | 31.95 | 33.249 |  | 25.4000 | 66.498 | 10.0000
33.249 |  | G33.249x2.309 | G 1 | 11 | B | 33.249 | 32.889 | 31.770 | 31.410 | 30.291
37.897 |  | G37.897x2.309 | G 1 1/8 | 11 | A | 37.897 | 37.537 | 36.418 | 36.238 | 34.939 |  |  | 34.939 | 35.579 | 36.418 | 36.598 | 37.897 |  | 28.5750 | 75.794 | 10.0000
37.897 |  | G37.897x2.309 | G 1 1/8 | 11 | B | 37.897 | 37.537 | 36.418 | 36.058 | 34.939
41.910 |  | G41.91x2.309 | G 1 1/4 | 11 | A | 41.910 | 41.550 | 40.431 | 40.251 | 38.952 |  |  | 38.952 | 39.592 | 40.431 | 40.611 | 41.910 |  | 31.7500 | 83.820 | 10.0000
41.910 |  | G41.91x2.309 | G 1 1/4 | 11 | B | 41.910 | 41.550 | 40.431 | 40.071 | 38.952
47.803 |  | G47.803x2.309 | G 1 1/2 | 11 | A | 47.803 | 47.443 | 46.324 | 46.144 | 44.845 |  |  | 44.845 | 45.485 | 46.324 | 46.504 | 47.803 |  | 38.1000 | 95.606 | 10.0000
47.803 |  | G47.803x2.309 | G 1 1/2 | 11 | B | 47.803 | 47.443 | 46.324 | 45.964 | 44.845
53.746 |  | G53.746x2.309 | G 1 3/4 | 11 | A | 53.746 | 53.386 | 52.267 | 52.087 | 50.788 |  |  | 50.788 | 51.428 | 52.267 | 52.447 | 53.746 |  | 44.4500 | 107.492 | 10.0000
53.746 |  | G53.746x2.309 | G 1 3/4 | 11 | B | 53.746 | 53.386 | 52.267 | 51.907 | 50.788
59.614 |  | G59.614x2.309 | G 2 | 11 | A | 59.614 | 59.254 | 58.135 | 57.955 | 56.656 |  |  | 56.656 | 57.296 | 58.135 | 58.315 | 59.614 |  | 50.8000 | 119.228 | 10.0000
59.614 |  | G59.614x2.309 | G 2 | 11 | B | 59.614 | 59.254 | 58.135 | 57.775 | 56.656
65.710 |  | G65.71x2.309 | G 2 1/4 | 11 | A | 65.710 | 65.276 | 64.231 | 64.014 | 62.752 |  |  | 62.752 | 63.392 | 64.231 | 64.448 | 65.710 |  | 57.1500 | 131.420 | 10.0000
65.710 |  | G65.71x2.309 | G 2 1/4 | 11 | B | 65.710 | 65.276 | 64.231 | 63.797 | 62.752
75.184 |  | G75.184x2.309 | G 2 1/2 | 11 | A | 75.184 | 74.750 | 73.705 | 73.488 | 72.226 |  |  | 72.226 | 72.866 | 73.705 | 73.922 | 75.184 |  |  | 150.368 | 10.0000
75.184 |  | G75.184x2.309 | G 2 1/2 | 11 | B | 75.184 | 74.750 | 73.705 | 73.271 | 72.226
81.534 |  | G81.534x2.309 | G 2 3/4 | 11 | A | 81.534 | 81.100 | 80.055 | 79.838 | 78.576 |  |  | 78.576 | 79.216 | 80.055 | 80.272 | 81.534 |  | 69.8500 | 163.068 | 10.0000
81.534 |  | G81.534x2.309 | G 2 3/4 | 11 | B | 81.534 | 81.100 | 80.055 | 79.621 | 78.576
87.884 |  | G87.884x2.309 | G 3 | 11 | A | 87.884 | 87.450 | 86.405 | 86.188 | 84.926 |  |  | 84.926 | 85.566 | 86.405 | 86.622 | 87.884 |  | 76.2000 | 175.768 | 10.0000
87.884 |  | G87.884x2.309 | G 3 | 11 | B | 87.884 | 87.450 | 86.405 | 85.971 | 84.926
100.330 |  | G100.33x2.309 | G 3 1/2 | 11 | A | 100.330 | 99.896 | 98.851 | 98.634 | 97.372 |  |  | 97.372 | 98.012 | 98.851 | 99.068 | 100.330 |  | 88.9000 | 200.660 | 10.0000
100.330 |  | G100.33x2.309 | G 3 1/2 | 11 | B | 100.330 | 99.896 | 98.851 | 98.417 | 97.372
113.030 |  | G113.03x2.309 | G 4 | 11 | A | 113.030 | 112.596 | 111.551 | 111.334 | 110.072 |  |  | 110.072 | 110.712 | 111.551 | 111.768 | 113.030 |  | 101.6000 | 226.060 | 10.0000
113.030 |  | G113.03x2.309 | G 4 | 11 | B | 113.030 | 112.596 | 111.551 | 111.117 | 110.072
125.730 |  | G125.73x2.309 | G 4 1/2 | 11 | A | 125.730 | 125.296 | 124.251 | 124.034 | 122.772 |  |  | 122.772 | 123.412 | 124.251 | 124.468 | 125.730 |  | 114.3000 | 251.460 | 10.0000
125.730 |  | G125.73x2.309 | G 4 1/2 | 11 | B | 125.730 | 125.296 | 124.251 | 123.817 | 122.772
138.430 |  | G138.43x2.309 | G 5 | 11 | A | 138.430 | 137.996 | 136.951 | 136.734 | 135.472 |  |  | 135.472 | 136.112 | 136.951 | 137.168 | 138.430 |  | 127.0000 | 276.860 | 10.0000
138.430 |  | G138.43x2.309 | G 5 | 11 | B | 138.430 | 137.996 | 136.951 | 136.517 | 135.472
151.130 |  | G151.13x2.309 | G 5 1/2 | 11 | A | 151.130 | 150.696 | 149.651 | 149.434 | 148.172 |  |  | 148.172 | 148.812 | 149.651 | 149.868 | 151.130 |  | 139.7000 | 302.260 | 10.0000
151.130 |  | G151.13x2.309 | G 5 1/2 | 11 | B | 151.130 | 150.696 | 149.651 | 149.217 | 148.172
163.830 |  | G163.83x2.309 | G 6 | 11 | A | 163.830 | 163.396 | 162.351 | 162.134 | 160.872 |  |  | 160.872 | 161.512 | 162.351 | 162.568 | 163.830 |  | 152.4000 | 327.660 | 10.0000
163.830 |  | G163.83x2.309 | G 6 | 11 | B | 163.830 | 163.396 | 162.351 | 161.917 | 160.872

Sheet: DIN Pipe Threads
M Q | DIN Pipe Threads |  | Sort Order - 18 |  | External |  |  |  |  |  |  | Internal
 |  |  |  |  |  | Major Dia |  | Pitch Dia |  | Minor Dia |  |  | Minor Dia |  | Pitch Dia |  | Major Dia |  | Tap Drill | Thread Depth | Thread Runouts
Size | Size Suffix | Thread Designation | Custom Thread Designation | TPI | Class | Max | Min | Max | Min | Max | Min | Class | Min | Max | Min | Max | Min | Max | Basic
7.723 |  | G7.723x0.907 | G 1/16 | 28 | A | 7.723 | 7.509 | 7.142 | 7.035 | 6.561 |  |  | 6.561 | 6.834 | 7.142 | 7.249 | 7.723 |  | 1.5875 | 15.446 | 4.5000
7.723 |  | G7.723x0.907 | G 1/16 | 28 | B | 7.723 | 7.509 | 7.142 | 6.928 | 6.561
9.728 |  | G9.728x0.907 | G 1/8 | 28 | A | 9.728 | 9.514 | 9.147 | 9.040 | 8.566 |  |  | 8.566 | 8.848 | 9.147 | 9.254 | 9.728 |  | 3.1750 | 19.456 | 4.5000
9.728 |  | G9.728x0.907 | G 1/8 | 28 | B | 9.728 | 9.514 | 9.147 | 8.933 | 8.566
13.157 |  | G13.157x1.337 | G 1/4 | 19 | A | 13.157 | 12.907 | 12.301 | 12.176 | 11.445 |  |  | 11.445 | 11.89 | 12.301 | 12.426 | 13.157 |  | 6.3500 | 26.314 | 6.5000
13.157 |  | G13.157x1.337 | G 1/4 | 19 | B | 13.157 | 12.907 | 12.301 | 12.051 | 11.445
16.662 |  | G16.662x1.337 | G 3/8 | 19 | A | 16.662 | 16.412 | 15.806 | 15.681 | 14.950 |  |  | 14.95 | 15.395 | 15.806 | 15.931 | 16.662 |  | 9.5250 | 33.324 | 6.5000
16.662 |  | G16.662x1.337 | G 3/8 | 19 | B | 16.662 | 16.412 | 15.806 | 15.556 | 14.950
20.955 |  | G20.955x1.814 | G 1/2 | 14 | A | 20.955 | 20.671 | 19.793 | 19.651 | 18.631 |  |  | 18.631 | 19.172 | 19.793 | 19.935 | 20.955 |  | 12.7000 | 41.910 | 8.5000
20.955 |  | G20.955x1.814 | G 1/2 | 14 | B | 20.955 | 20.671 | 19.793 | 19.509 | 18.631
22.911 |  | G22.911x1.814 | G 5/8 | 14 | A | 22.911 | 22.627 | 21.749 | 21.607 | 20.587 |  |  | 20.587 | 21.128 | 21.749 | 21.891 | 22.911 |  |  | 45.822 | 8.5000
22.911 |  | G22.911x1.814 | G 5/8 | 14 | B | 22.911 | 22.627 | 21.749 | 21.465 | 20.587
26.441 |  | G26.441x1.814 | G 3/4 | 14 | A | 26.441 | 26.157 | 25.279 | 25.137 | 24.117 |  |  | 24.117 | 24.658 | 25.279 | 25.421 | 26.441 |  | 15.8750 | 52.882 | 8.5000
26.441 |  | G26.441x1.814 | G 3/4 | 14 | B | 26.441 | 26.157 | 25.279 | 24.995 | 24.117
30.201 |  | G30.201x1.814 | G 7/8 | 14 | A | 30.201 | 29.917 | 29.039 | 28.897 | 27.877 |  |  | 27.877 | 28.418 | 29.039 | 29.181 | 30.201 |  | 22.2250 | 60.402 | 8.5000
30.201 |  | G30.201x1.814 | G 7/8 | 14 | B | 30.201 | 29.917 | 29.039 | 28.755 | 27.877
33.249 |  | G33.249x2.309 | G 1 | 11 | A | 33.249 | 32.889 | 31.770 | 31.590 | 30.291 |  |  | 30.291 | 30.931 | 31.77 | 31.95 | 33.249 |  | 25.4000 | 66.498 | 10.5000
33.249 |  | G33.249x2.309 | G 1 | 11 | B | 33.249 | 32.889 | 31.770 | 31.410 | 30.291
37.897 |  | G37.897x2.309 | G 1 1/8 | 11 | A | 37.897 | 37.537 | 36.418 | 36.238 | 34.939 |  |  | 34.939 | 35.579 | 36.418 | 36.598 | 37.897 |  | 28.5750 | 75.794 | 10.5000
37.897 |  | G37.897x2.309 | G 1 1/8 | 11 | B | 37.897 | 37.537 | 36.418 | 36.058 | 34.939
41.910 |  | G41.91x2.309 | G 1 1/4 | 11 | A | 41.910 | 41.550 | 40.431 | 40.251 | 38.952 |  |  | 38.952 | 39.592 | 40.431 | 40.611 | 41.910 |  | 31.7500 | 83.820 | 10.5000
41.910 |  | G41.91x2.309 | G 1 1/4 | 11 | B | 41.910 | 41.550 | 40.431 | 40.071 | 38.952
47.803 |  | G47.803x2.309 | G 1 1/2 | 11 | A | 47.803 | 47.443 | 46.324 | 46.144 | 44.845 |  |  | 44.845 | 45.485 | 46.324 | 46.504 | 47.803 |  | 38.1000 | 95.606 | 10.5000
47.803 |  | G47.803x2.309 | G 1 1/2 | 11 | B | 47.803 | 47.443 | 46.324 | 45.964 | 44.845
53.746 |  | G53.746x2.309 | G 1 3/4 | 11 | A | 53.746 | 53.386 | 52.267 | 52.087 | 50.788 |  |  | 50.788 | 51.428 | 52.267 | 52.447 | 53.746 |  | 44.4500 | 107.492 | 10.5000
53.746 |  | G53.746x2.309 | G 1 3/4 | 11 | B | 53.746 | 53.386 | 52.267 | 51.907 | 50.788
59.614 |  | G59.614x2.309 | G 2 | 11 | A | 59.614 | 59.254 | 58.135 | 57.955 | 56.656 |  |  | 56.656 | 57.296 | 58.135 | 58.315 | 59.614 |  | 50.8000 | 119.228 | 10.5000
59.614 |  | G59.614x2.309 | G 2 | 11 | B | 59.614 | 59.254 | 58.135 | 57.775 | 56.656
65.710 |  | G65.71x2.309 | G 2 1/4 | 11 | A | 65.710 | 65.276 | 64.231 | 64.014 | 62.752 |  |  | 62.752 | 63.392 | 64.231 | 64.448 | 65.710 |  | 57.1500 | 131.420 | 10.5000
65.710 |  | G65.71x2.309 | G 2 1/4 | 11 | B | 65.710 | 65.276 | 64.231 | 63.797 | 62.752
75.184 |  | G75.184x2.309 | G 2 1/2 | 11 | A | 75.184 | 74.750 | 73.705 | 73.488 | 72.226 |  |  | 72.226 | 72.866 | 73.705 | 73.922 | 75.184 |  |  | 150.368 | 10.5000
75.184 |  | G75.184x2.309 | G 2 1/2 | 11 | B | 75.184 | 74.750 | 73.705 | 73.271 | 72.226
81.534 |  | G81.534x2.309 | G 2 3/4 | 11 | A | 81.534 | 81.100 | 80.055 | 79.838 | 78.576 |  |  | 78.576 | 79.216 | 80.055 | 80.272 | 81.534 |  | 69.8500 | 163.068 | 10.5000
81.534 |  | G81.534x2.309 | G 2 3/4 | 11 | B | 81.534 | 81.100 | 80.055 | 79.621 | 78.576
87.884 |  | G87.884x2.309 | G 3 | 11 | A | 87.884 | 87.450 | 86.405 | 86.188 | 84.926 |  |  | 84.926 | 85.566 | 86.405 | 86.622 | 87.884 |  | 76.2000 | 175.768 | 10.5000
87.884 |  | G87.884x2.309 | G 3 | 11 | B | 87.884 | 87.450 | 86.405 | 85.971 | 84.926
100.330 |  | G100.33x2.309 | G 3 1/2 | 11 | A | 100.330 | 99.896 | 98.851 | 98.634 | 97.372 |  |  | 97.372 | 98.012 | 98.851 | 99.068 | 100.330 |  | 88.9000 | 200.660 | 10.5000
100.330 |  | G100.33x2.309 | G 3 1/2 | 11 | B | 100.330 | 99.896 | 98.851 | 98.417 | 97.372
113.030 |  | G113.03x2.309 | G 4 | 11 | A | 113.030 | 112.596 | 111.551 | 111.334 | 110.072 |  |  | 110.072 | 110.712 | 111.551 | 111.768 | 113.030 |  | 101.6000 | 226.060 | 10.5000
113.030 |  | G113.03x2.309 | G 4 | 11 | B | 113.030 | 112.596 | 111.551 | 111.117 | 110.072
125.730 |  | G125.73x2.309 | G 4 1/2 | 11 | A | 125.730 | 125.296 | 124.251 | 124.034 | 122.772 |  |  | 122.772 | 123.412 | 124.251 | 124.468 | 125.730 |  | 114.3000 | 251.460 | 10.5000
125.730 |  | G125.73x2.309 | G 4 1/2 | 11 | B | 125.730 | 125.296 | 124.251 | 123.817 | 122.772
138.430 |  | G138.43x2.309 | G 5 | 11 | A | 138.430 | 137.996 | 136.951 | 136.734 | 135.472 |  |  | 135.472 | 136.112 | 136.951 | 137.168 | 138.430 |  | 127.0000 | 276.860 | 10.5000
138.430 |  | G138.43x2.309 | G 5 | 11 | B | 138.430 | 137.996 | 136.951 | 136.517 | 135.472
151.130 |  | G151.13x2.309 | G 5 1/2 | 11 | A | 151.130 | 150.696 | 149.651 | 149.434 | 148.172 |  |  | 148.172 | 148.812 | 149.651 | 149.868 | 151.130 |  | 139.7000 | 302.260 | 10.5000
151.130 |  | G151.13x2.309 | G 5 1/2 | 11 | B | 151.130 | 150.696 | 149.651 | 149.217 | 148.172
163.830 |  | G163.83x2.309 | G 6 | 11 | A | 163.830 | 163.396 | 162.351 | 162.134 | 160.872 |  |  | 160.872 | 161.512 | 162.351 | 162.568 | 163.830 |  | 152.4000 | 327.660 | 10.5000
163.830 |  | G163.83x2.309 | G 6 | 11 | B | 163.830 | 163.396 | 162.351 | 161.917 | 160.872

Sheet: BSP Pipe Threads
M Q | BSP Pipe Threads |  | Sort Order - 19 |  | External |  |  |  |  |  |  | Internal
 |  |  |  |  |  | Major Dia |  | Pitch Dia |  | Minor Dia |  |  | Minor Dia |  | Pitch Dia |  | Major Dia |  | Tap Drill | Thread Depth | Thread Runouts
Size | Size Suffix | Thread Designation | Custom Thread Designation | TPI | Class | Max | Min | Max | Min | Max | Min | Class | Min | Max | Min | Max | Min | Max | Basic |  | Basic
1/16 |  | G 1/16-28 | G 1/16-28 | 28 | A | 7.723 | 7.509 | 7.142 | 7.035 | 6.561 |  |  | 6.561 | 6.834 | 7.142 | 7.249 | 7.723 |  | 6.6000 | 15.4460 | 4.5000
1/16 |  | G 1/16-28 | G 1/16-28 | 28 | B | 7.723 | 7.509 | 7.142 | 7.035 | 6.561
1/8 |  | G 1/8-28 | G 1/8-28 | 28 | A | 9.728 | 9.514 | 9.147 | 9.040 | 8.566 |  |  | 8.566 | 8.848 | 9.147 | 9.254 | 9.728 |  | 8.7300 | 19.4560 | 4.5000
1/8 |  | G 1/8-28 | G 1/8-28 | 28 | B | 9.728 | 9.514 | 9.147 | 9.040 | 8.566
1/4 |  | G 1/4-19 | G 1/4-19 | 19 | A | 13.157 | 12.907 | 12.301 | 12.176 | 11.445 |  |  | 11.445 | 11.89 | 12.301 | 12.426 | 13.157 |  | 11.8000 | 26.3140 | 6.5000
1/4 |  | G 1/4-19 | G 1/4-19 | 19 | B | 13.157 | 12.907 | 12.301 | 12.176 | 11.445
3/8 |  | G 3/8-19 | G 3/8-19 | 19 | A | 16.662 | 16.412 | 15.806 | 15.681 | 14.950 |  |  | 14.95 | 15.395 | 15.806 | 15.931 | 16.662 |  | 15.2500 | 33.3240 | 6.5000
3/8 |  | G 3/8-19 | G 3/8-19 | 19 | B | 16.662 | 16.412 | 15.806 | 15.681 | 14.950
1/2 |  | G 1/2-14 | G 1/2-14 | 14 | A | 20.955 | 20.671 | 19.793 | 19.651 | 18.631 |  |  | 18.631 | 19.172 | 19.793 | 19.935 | 20.955 |  | 19.0500 | 41.9100 | 8.5000
1/2 |  | G 1/2-14 | G 1/2-14 | 14 | B | 20.955 | 20.671 | 19.793 | 19.651 | 18.631
5/8 |  | G 5/8-14 | G 5/8-14 | 14 | A | 22.911 | 22.627 | 21.749 | 21.607 | 20.587 |  |  | 20.587 | 21.128 | 21.749 | 21.891 | 22.911 |  | 21.0000 | 45.8220 | 8.5000
5/8 |  | G 5/8-14 | G 5/8-14 | 14 | B | 22.911 | 22.627 | 21.749 | 21.607 | 20.587
3/4 |  | G 3/4-14 | G 3/4-14 | 14 | A | 26.441 | 26.157 | 25.279 | 25.137 | 24.117 |  |  | 24.117 | 24.658 | 25.279 | 25.421 | 26.441 |  | 24.5000 | 52.8820 | 8.5000
3/4 |  | G 3/4-14 | G 3/4-14 | 14 | B | 26.441 | 26.157 | 25.279 | 25.137 | 24.117
7/8 |  | G 7/8-14 | G 7/8-14 | 14 | A | 30.201 | 29.917 | 29.039 | 28.897 | 27.877 |  |  | 27.877 | 28.418 | 29.039 | 29.181 | 30.201 |  | 28.2500 | 60.4020 | 8.5000
7/8 |  | G 7/8-14 | G 7/8-14 | 14 | B | 30.201 | 29.917 | 29.039 | 28.897 | 27.877
1 |  | G 1-11 | G 1-11 | 11 | A | 33.249 | 32.889 | 31.770 | 31.590 | 30.291 |  |  | 30.291 | 30.931 | 31.77 | 31.95 | 33.249 |  | 30.7500 | 66.4980 | 10.0000
1 |  | G 1-11 | G 1-11 | 11 | B | 33.249 | 32.889 | 31.770 | 31.590 | 30.291
1 1/4 |  | G 1 1/4-11 | G 1 1/4-11 | 11 | A | 41.910 | 41.550 | 40.431 | 40.251 | 38.952 |  |  | 38.952 | 39.592 | 40.431 | 40.611 | 41.910 |  | 39.5000 | 83.8200 | 10.0000
1 1/4 |  | G 1 1/4-11 | G 1 1/4-11 | 11 | B | 41.910 | 41.550 | 40.431 | 40.251 | 38.952
1 1/2 |  | G 1 1/2-11 | G 1 1/2-11 | 11 | A | 47.803 | 47.443 | 46.324 | 46.144 | 44.845 |  |  | 44.845 | 45.485 | 46.324 | 46.504 | 47.803 |  | 45.5000 | 95.6060 | 10.0000
1 1/2 |  | G 1 1/2-11 | G 1 1/2-11 | 11 | B | 47.803 | 47.443 | 46.324 | 46.144 | 44.845
1 3/4 |  | G 1 3/4-11 | G 1 3/4-11 | 11 | A | 53.746 | 53.386 | 52.267 | 52.087 | 50.788 |  |  | 50.788 | 51.428 | 52.267 | 52.447 | 53.746 |  | 51.0000 | 107.4920 | 10.0000
1 3/4 |  | G 1 3/4-11 | G 1 3/4-11 | 11 | B | 53.746 | 53.386 | 52.267 | 52.087 | 50.788
2 |  | G 2-11 | G 2-11 | 11 | A | 59.614 | 59.254 | 58.135 | 57.955 | 56.656 |  |  | 56.656 | 57.296 | 58.135 | 58.315 | 59.614 |  | 57.0000 | 119.2280 | 10.0000
2 |  | G 2-11 | G 2-11 | 11 | B | 59.614 | 59.254 | 58.135 | 57.955 | 56.656
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

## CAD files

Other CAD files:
solid_Modeling/CapacityMonitorAssembly_AutodeskInventor/Templates/English/am_ansi.dwg
solid_Modeling/CapacityMonitorAssembly_AutodeskInventor/Templates/Metric/BSI.dwg
solid_Modeling/CapacityMonitorAssembly_AutodeskInventor/Templates/Standard.dwg
solid_Modeling/CapacityMonitorAssembly_AutodeskInventor/Templates/English/ANSI (in).dwg
solid_Modeling/CapacityMonitorAssembly_AutodeskInventor/Templates/Metric/am_bsi.dwg
solid_Modeling/CapacityMonitorAssembly_AutodeskInventor/Templates/Metric/DIN.dwg
solid_Modeling/CapacityMonitorAssembly_AutodeskInventor/Templates/Metric/am_iso.dwg
solid_Modeling/CapacityMonitorAssembly_AutodeskInventor/Templates/Metric/JIS.dwg
solid_Modeling/CapacityMonitorAssembly_AutodeskInventor/Templates/Metric/am_jis.dwg
solid_Modeling/CapacityMonitorAssembly_AutodeskInventor/Templates/Metric/ISO.dwg
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

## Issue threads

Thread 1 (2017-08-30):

Not a real issue just didn't know how to contact you

matt-desmarais, 2017-08-30:
I have an idea of teaming up and combining my smart crosshair system with your project
https://github.com/matt-desmarais/P0Wcrosshair

SMR404, 2017-08-30:
That's a pretty cool idea! Do you mean to attach your system to a gun that
also has my system? Or do you mean to remake my system for an airsoft gun?

Also, I apologize, but I won't have any more time to work on my project or
help you. I thought I would but I don't. Sorry.

But feel free to take my concept for yourself, that's the beauty of open
source.

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

matt-desmarais, 2017-08-30:
Not remake for airsoft I would reprogram my crosshairs for bullets

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

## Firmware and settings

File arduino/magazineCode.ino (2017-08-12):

/*
Modified version of Samy Kamkar's (@samyk) magspoof code.
@miaoski converted the original magspoof code to work with arduino instead of Atiny85.
I (@SMR404) took miaoski's code and added the dynamic tracks and analog softpot reading.

If you use this code, you will need to calibrate your magazine using the softpot debug code LinearSoftPotTest.ino
Record the value of the analog reading at every capacity (with magazine inserted into complete rifle and alter the
array, capacityAnalogValues[], below.

*/


#include <stdlib.h>

void setPolarity(int polarity);
void playBit(int bit);


#include <time.h>       /* time */
#define PIN_A    3      // left pin, to L293D pin 2
#define PIN_B    4      // right pin, to L293D pin 7
#define ENABLE_PIN 13   //the onboard led

#define SOFT_POT_PIN A0  //analog pin 2, goes to the resistor or potentiometer
#define DRIVING_PIN  11//the pin that drives the potentiometer
#define CLOCK_US 400
#define BETWEEN_ZERO 53 // 53 zeros between track1 & 2


int polarity = 0;
char revTrack[80];

const int sublen[] = { 32, 48, 48 };
const int bitlen[] = {  7,  5,  5 };

//track value, refreshed twice a second
char* tracks[] = {"^01^?"}; // Track 1(which is all we need, track 2 is useless); %BPAN^NAME^YYMMSSSCVV? + LRC





//These are the average analogRead Values for each different capacity of the magazine. 31 array elements represents the possible number of rounds (0 through 30)
/*
This array was created by measuring analog values when the magazine was placed in the lower receiver
with no upper receiver attached, skewing the values (the bolt pushes down on the follower, changing the value)
It has no practical application besides debugging 
const int capacityAnalogValues[31] = {25, 45, 71, 101, 121, 145, 165, 186, 212, 234,
                                      254, 277, 298, 324, 346, 372, 393, 420, 443, 471,
                                      496, 528, 554, 590, 621, 660 , 693, 737, 783, 825, 865
                                     };   //last value is made up, extrapolated from the previous pattern
*/
//This is a corrected array recorded while the magazine was firmly placed in the gun with the upper receiver attached, resulting in useful values
const int capacityAnalogValues[31] = {38, 58, 76, 105, 128, 150, 172, 196, 218, 240, 259,
                                      284, 306, 330, 355, 383, 406, 430, 457, 485, 513, 542, 
                                      573, 603, 640, 677, 716, 751, 798, 844, 880
                                     }; //last value is made up, extrapolated from the previous pattern

int currentCapacity = 0;
int previousCapacity = 0;

void setup() {


  //srand (time(NULL));         //debug
  pinMode(PIN_A, OUTPUT);
  pinMode(PIN_B, OUTPUT);
  Serial.begin(9600);
  Serial.print("Start");
  storeRevTrack(2);

  pinMode(SOFT_POT_PIN, INPUT);    
  pinMode(DRIVING_PIN, OUTPUT);   //drives the soft pot
  digitalWrite(DRIVING_PIN, HIGH);
}

// Set the polarity of the electromagnet.
void setPolarity(int polarity) {
  if (polarity) {
    digitalWrite(PIN_B, LOW);
    digitalWrite(PIN_A, HIGH);
  } else {
    digitalWrite(PIN_A, LOW);
    digitalWrite(PIN_B, HIGH);
  }
}

void playBit(int bit) {
  polarity ^= 1;
  setPolarity(polarity);
  delayMicroseconds(CLOCK_US);

  if (bit == 1) {
    polarity ^= 1;
    setPolarity(polarity);
  }

  delayMicroseconds(CLOCK_US);
}

// when reversing
void reverseTrack(int track) {
  int i = 0;
  track--; // index 0
  polarity = 0;

  while(revTrack[i++] != '\0');
  i--;
  while(i--)
    for (int j = bitlen[track]-1; j >= 0; j--)
      playBit((revTrack[i] >> j) & 1);
}

// plays out a full track, calculating CRCs and LRC
void playTrack(int track)
{
  int tmp, crc, lrc = 0;
  track--; // index 0
  polarity = 0;

  // enable H-bridge and LED
  digitalWrite(ENABLE_PIN, HIGH);

  // First put out a bunch of leading zeros.
  for(int i = 0; i < 25; i++)
    playBit(0);

  Serial.print("Sending: ");
  for(int i = 0; tracks[track][i] != '\0'; i++) {
    Serial.print(tracks[track][i]);     // The delay that Track 1 needs.
    crc = 1;
    tmp = tracks[track][i] - sublen[track];

    for(int j = 0; j < bitlen[track]-1; j++) {
      crc ^= (tmp & 1);
      lrc ^= (tmp & 1) << j;
      playBit(tmp & 1);
      tmp >>= 1;
    }
    playBit(crc);
  }
  Serial.println();

  // finish calculating and send last "byte" (LRC)
  tmp = lrc;
  crc = 1;
  for(int j = 0; j < bitlen[track]-1; j++) {
    crc ^= tmp & 1;
    playBit(tmp & 1);
    tmp >>= 1;
  }
  playBit(crc);

  // if track 1, play 2nd track in reverse (like swiping back?)
/*
  if(track == 0) {
    for(int i = 0; i < BETWEEN_ZERO; i++)
      playBit(0);
    reverseTrack(2);
  }
  */
  // finish with 0's
  for (int i = 0; i < 25; i++)
    playBit(0);

  digitalWrite(PIN_A, LOW);
  digitalWrite(PIN_B, LOW);
  digitalWrite(ENABLE_PIN, LOW);
}



// stores track for reverse usage later
void storeRevTrack(int track) {
  int i, tmp, crc, lrc = 0;
  track--; // index 0
  polarity = 0;

  for (i = 0; tracks[track][i] != '\0'; i++) {
    crc = 1;
    tmp = tracks[track][i] - sublen[track];

    for (int j = 0; j < bitlen[track]-1; j++) {
      crc ^= tmp & 1;
      lrc ^= (tmp & 1) << j;
      tmp & 1 ?
        (revTrack[i] |= 1 << j) :
        (revTrack[i] &= ~(1 << j));
      tmp >>= 1;
    }
    crc ?
      (revTrack[i] |= 1 << 4) :
      (revTrack[i] &= ~(1 << 4));
  } 

  // finish calculating and send last "byte" (LRC)
  tmp = lrc;
  crc = 1;
  for (int j = 0; j < bitlen[track]-1; j++) {
    crc ^= tmp & 1;
    tmp & 1 ?
      (revTrack[i] |= 1 << j) :
      (revTrack[i] &= ~(1 << j));
    tmp >>= 1;
  }
  crc ?
    (revTrack[i] |= 1 << 4) :
    (revTrack[i] &= ~(1 << 4));

  i++;
  revTrack[i] = '\0';
}


//read voltage or resistance using analog input and use it to calculate a capacity
int getCapacity()
{ 

  
  ////////////    debugging to make sure magspoof is working, even if you don't have a softpot connected
//  int number;
//  number = rand() % 10 + 1;
//  return number;
  //////////////////
  
  int currentCapacity;
  int softPotADC;              //analog reading
  int calc;                   //placeholder variable used in calculating capacity
  
  softPotADC = analogRead(SOFT_POT_PIN);    //get reading from analog pin


  ////////////////////////////////////////////////////////
  //if capacity is 30
  //For the demonstated magazine, the follower passed the softpot at 30 rounds, resulting in a value of zero 
  if (softPotADC == 0)
  {
    Serial.println("The capacity is 30");
    currentCapacity = (int) 30;
  }
  else
  {
    int i = 1;
    //Covers capacities 1 - 29
    while ((i <= 30))
    {
      calc = (((capacityAnalogValues[i] - capacityAnalogValues[i - 1]) / 2) + capacityAnalogValues[i - 1]);
      if (calc >= softPotADC)            //if the analog value is above the lower threshold of the average analog capacity value
      {
        currentCapacity = (int)(i - 1);


        //these two lines are essential to the program and I don't really understand why. 
        //Try removing them and you'll see that this code doesn't function as intended (tracks[] has rubbish characters appended to it for some reason). 
        //Could be a timing issue? Anyway, solid programming standards /s
        Serial.println("The capacity is ");
        Serial.print(currentCapacity);

        
        break;
      }
      i++;
    }
  }
///////////////////////////////////////////////////////////////////////

  return currentCapacity;
}


//boolean indicator of whether the capacity value has changed
bool capacityChanged(int currentCapacity, int previousCapacity)
{
  if(!(currentCapacity == previousCapacity))
  {
    return 1;
  }
  else
  {
    return 0;
  }
}


void updateCapacityChar(int currentCapacity, char* tracks[])    //update the tracks to hold capacity value
{
      tracks[0][0] = '%';   //prefix
      tracks[0][1] = '^';
      tracks[0][2] = '0' + (currentCapacity/10);    //tens place
      tracks[0][3] = '0' + (currentCapacity%10);    //ones place
      tracks[0][4] = '^';
      tracks[0][5] = '?';   //suffix
}

void loop() {
//  memset(revTrack, 1, sizeof(revTrack));
    currentCapacity = getCapacity();      //read voltage or resistance and get capacity
//  if(capacityChanged(currentCapacity, previousCapacity))    //if the value has changed, send the new capacity value
//  {
    updateCapacityChar(currentCapacity, tracks);
    Serial.println(currentCapacity);
    Serial.println(tracks[0]); 
    playTrack(1);
    previousCapacity = currentCapacity;
    delay(500);
//  }
//  else
//  {
//    delay(40);
//  }
}

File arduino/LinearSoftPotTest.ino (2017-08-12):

/******************************************************************************
  (@SMR404) August 2017
  Edited version of SoftPot_Example.ino
  
  Originally an example sketch for SparkFun's soft membrane potentiometer
  (https://www.sparkfun.com/products/8680)
  Jim Lindblom @ SparkFun Electronics
  April 28, 2016

  - Connect the softpot's outside pins to Digital pin 11 and GND (the outer pin with an arrow
  indicator should be connected to GND).
  - Connect the middle pin to A0.


  Development environment specifics:
  Arduino 1.6.7
******************************************************************************/
const int SOFT_POT_PIN = A0; // Pin connected to softpot wiper
const int DRIVING_PIN = 11;   //drives the softpot
const int GRAPH_LENGTH = 40; // Length of line graph


//These are the average analogRead Values for each different capacity of the magazine. 31 array elements represents the possible number of rounds (0 through 30)
//Record the analog values printed to the monitor and change this array until you are happy with how it calculates the magazine capacity
const int capacityAnalogValues[31] = {25, 45, 71, 101, 121, 145, 165, 186, 212, 234,
                                      254, 277, 298, 324, 346, 372, 393, 420, 443, 471,
                                      496, 528, 554, 590, 621, 660 , 693, 737, 783, 825, 865
                                     };                                                                       //the final value of 865 is made up. The 30th round pushes the follower past the sensor and gives a reading of 0

void setup()
{
  Serial.begin(9600);
  pinMode(SOFT_POT_PIN, INPUT);
  pinMode(DRIVING_PIN, OUTPUT);
  digitalWrite(DRIVING_PIN, HIGH);
}

void loop()
{
  // Read in the soft pot's ADC value
  int calc;
  int softPotADC = analogRead(SOFT_POT_PIN);

  //if capacity is 30
  if (softPotADC == 0)      //value is zero when capacity is zero (the follower pushes past the softPot, may differ in your case)
  {
    Serial.println("The capacity is 30");
  }
  else
  {
    int i = 1;
    //Covers capacities 1 - 29
    while ((i <= 30))
    {
      calc = (((capacityAnalogValues[i] - capacityAnalogValues[i - 1]) / 2) + capacityAnalogValues[i - 1]);
      if (calc >= softPotADC)            //if the analog value is above the lower threshold of the average analog capacity value
      {
        Serial.print("The capacity is ");
        Serial.print((i - 1));
        break;
      }
      i++;
    }
  }
  Serial.println("\nANALOG READ VALUE: (" + String(softPotADC) + ")");
  delay(700);
}

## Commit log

2017-08-12 Create magazineCode.ino
    This is the code for the Arduino located on the magazine. It is a modified version of Samy Kamkar's (@samyk) magspoof which has been converted to be run on arduino by @miaoski. I (@SMR404) added in t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
2017-08-12 Create LinearSoftPotTest.ino
    Use this to calibrate the magazine
